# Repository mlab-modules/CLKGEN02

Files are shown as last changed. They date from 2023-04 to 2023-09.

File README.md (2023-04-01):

[Czech](./README.cs.md)
<!--- module --->
# CLKGEN02A
<!--- Emodule --->

<!--- subtitle --->Universal module for crystal oscillators<!--- Esubtitle --->

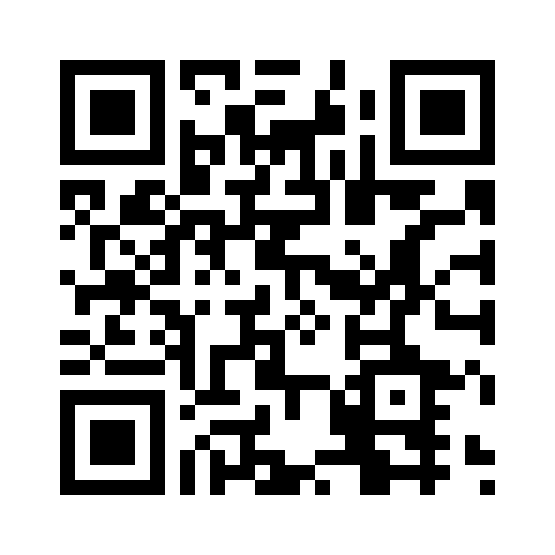
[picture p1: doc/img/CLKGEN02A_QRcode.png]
CLKGEN02A


<!--- description --->The module comprises a plurality of housings for mounting a variety of crystal oscillators.<!--- Edescription --->

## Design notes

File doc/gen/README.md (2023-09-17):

# PCB

Board size: 19.81x40.13 mm (0.78x1.58 inches)

- This is the size of the rectangle that contains the board
- Thickness: 1.6 mm (63 mils)
- Material: FR4
- Finish: HAL
- Layers: 2
- Copper thickness: 35 µm

Solder mask: TOP / BOTTOM

- Color: Green

Silk screen: TOP / BOTTOM

- Color: White

# Important sizes

Clearance: 0.2 mm (8 mils)

Track width: 0.3 mm (12 mils)

- By design rules: 0.2 mm (8 mils)

Drill: 0.5 mm (20 mils)

- Vias: 0.5 mm (20 mils) [Design: 0.4 mm (16 mils)]
- Pads: 0.7 mm (28 mils)
- The above values are real drill sizes, they add 0.1 mm (4 mils) to plated holes (PTH)

Via: 0.6/0.4 mm (24/16 mils)

- By design rules: 0.4/0.3 mm (16/12 mils)
- Micro via: yes [0.2/0.1 mm (8/4 mils)]
- Buried/blind via: yes
- Total: 5 (thru: 5 buried/blind: 0 micro: 0)

Outer Annular Ring: 0.05 mm (2 mils)

- By design rules: 0.26 mm (10 mils)

Eurocircuits class: 10B
- Using min drill 0.5 mm for an OAR of 0.05 mm

# General stats

Components count: (SMD/THT)

- Top: 0/8 (THT)
- Bottom: 6/7 (SMD + THT)

Defined tracks:

- 0.3 mm (12 mils)
- 0.4 mm (16 mils)
- 0.5 mm (20 mils)
- 0.6 mm (24 mils)
- 0.7 mm (28 mils)
- 0.8 mm (31 mils)
- 0.9 mm (35 mils)

Used tracks:

- 0.3 mm (12 mils) (23) defined: yes
- 0.9 mm (35 mils) (48) defined: yes

Defined vias:

Used vias:

- 0.6/0.4 mm (24/16 mils) (Count: 1, Aspect: 2.7 A) defined: no
- 0.8/0.4 mm (31/16 mils) (Count: 4, Aspect: 2.0 A) defined: no

Holes (excluding vias):

- 0.6 mm (24 mils) (4)
- 0.89 mm (35 mils) (14)
- 3.0 mm (118 mils) (4)

Oval holes:

Drill tools (including vias and computing adjusts and rounding):

- 0.5 mm (20 mils) (5)
- 0.7 mm (28 mils) (4)
- 1.0 mm (39 mils) (14)
- 3.1 mm (122 mils) (4)

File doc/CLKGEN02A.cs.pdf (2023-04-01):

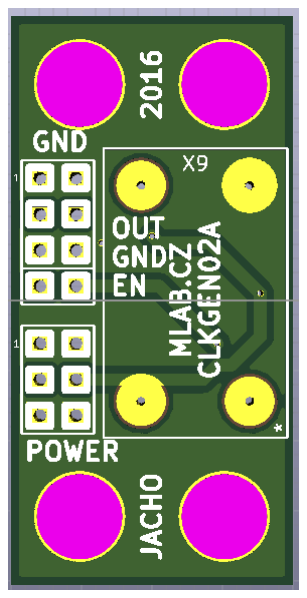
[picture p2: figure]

CLKGEN02A / 2017-02-20 / jacho/ http://www.mlab.cz | 1 / 4
CLKGEN02A | MLAB

# Krystalový oscilátor

Jan Chroust

Univerzální modul pro krystalový oscilátor s osmy typy pouzder.

# 1. Technické parametry

Parametr | Hodnota | Poznámka
Napájení | Dle zvoleného oscilátoru
Rozměry | 40.13 x 20.32 x 16 mm | Výška nad základní deskou

CLKGEN02A | MLAB

# 2. Popis konstrukce

## 2.1. Popis

Modul byl navržen jako univerzální pro osazení krystalovými oscilátory v osmy pouzdrech. Jedná se o tyto řady krystalových oscilátorů:

ASFL1
CFPS-72,73
ISM92 – R1=0R R2=nic
ISM97
I533_1534_1733_1734
ISM81
ISM95
OSC-F

CLKGEN02A | MLAB

## 2.2. Zapojení

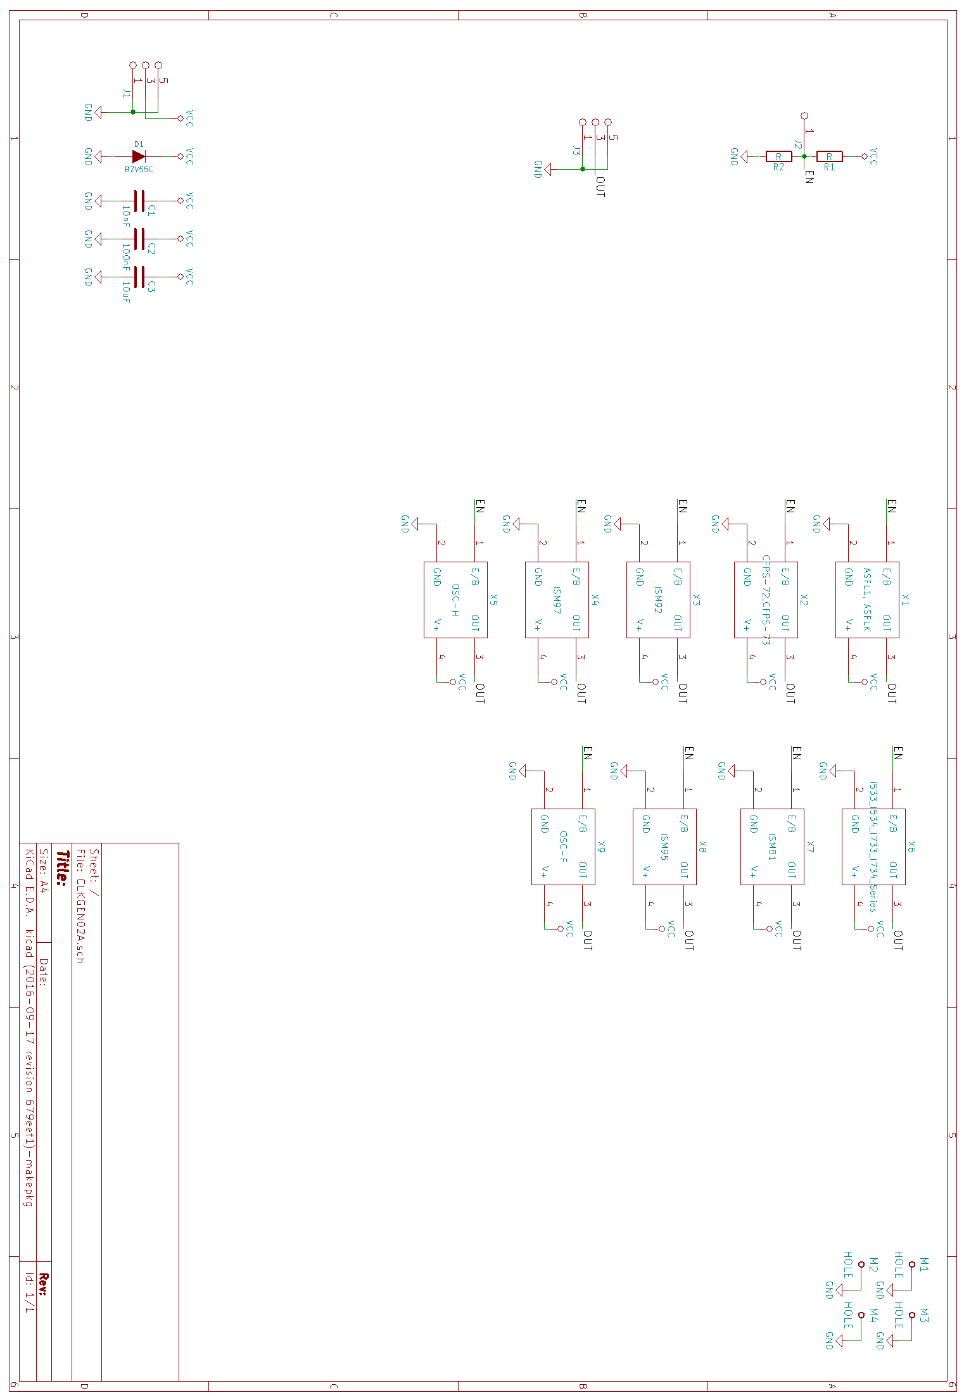
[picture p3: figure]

CLKGEN02A | MLAB

# 3. Osazení a oživení

## 3.1. Osazení

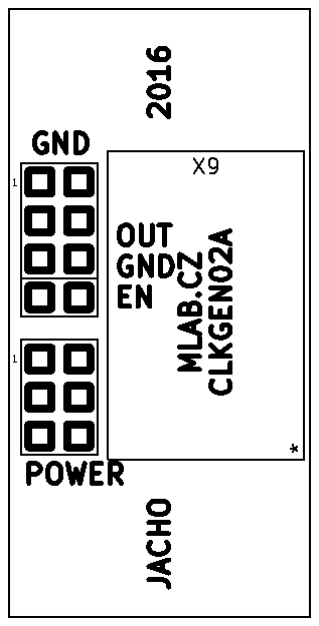
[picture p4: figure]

## 3.2. Rozpis součástek

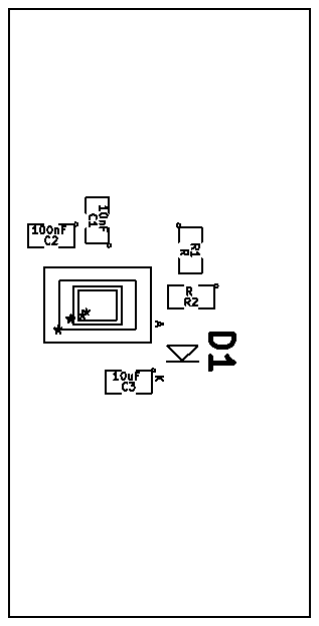
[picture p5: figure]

Označení | Typ | Pouzdro | Počet
C1 | 10nF | SMD-0805 | 1
C2 | 100nF | SMD-0805 | 1
C3 | 10uF | SMD-0805 | 1
J1,J3 | JUMP_3X2 | Straight_2x03 | 2
M1,M2,M3,M4 | HOLE | MountingHole_3mm | 4
R1,R2 | R | SMD-0805 | 2
X1 | ASFL1, ASFLK | ASFL1 | 1
X2 | CFPS-72,CFPS-73 | CFPS-72,73 | 1
X3 | ISM92 | ISM92 | 1
X4 | ISM97 | ISM97 | 1
X6 | I533_I534_I733_I734_Series | I533_1534_1733_1734 | 1
X7 | ISM81 | ISM81 | 1
X8 | ISM95 | ISM95 | 1
X9 | OSC-F | OSC-F | 1
J2 | JUMP_2x1 | Straight_1x02 | 1
D1 | BZV55C | Diode-MiniMELF_Standard | 1

## 3.3. Oživení

Není co oživovat. Je dobré provést kontrolu na zkraty.

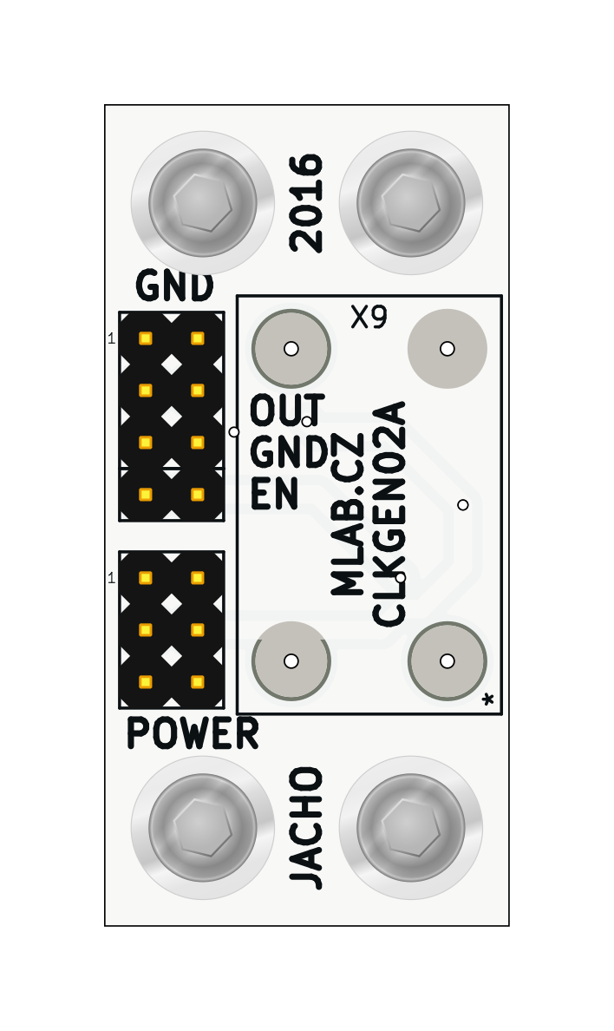
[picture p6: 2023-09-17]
doc/gen/img/CLKGEN02-top.png

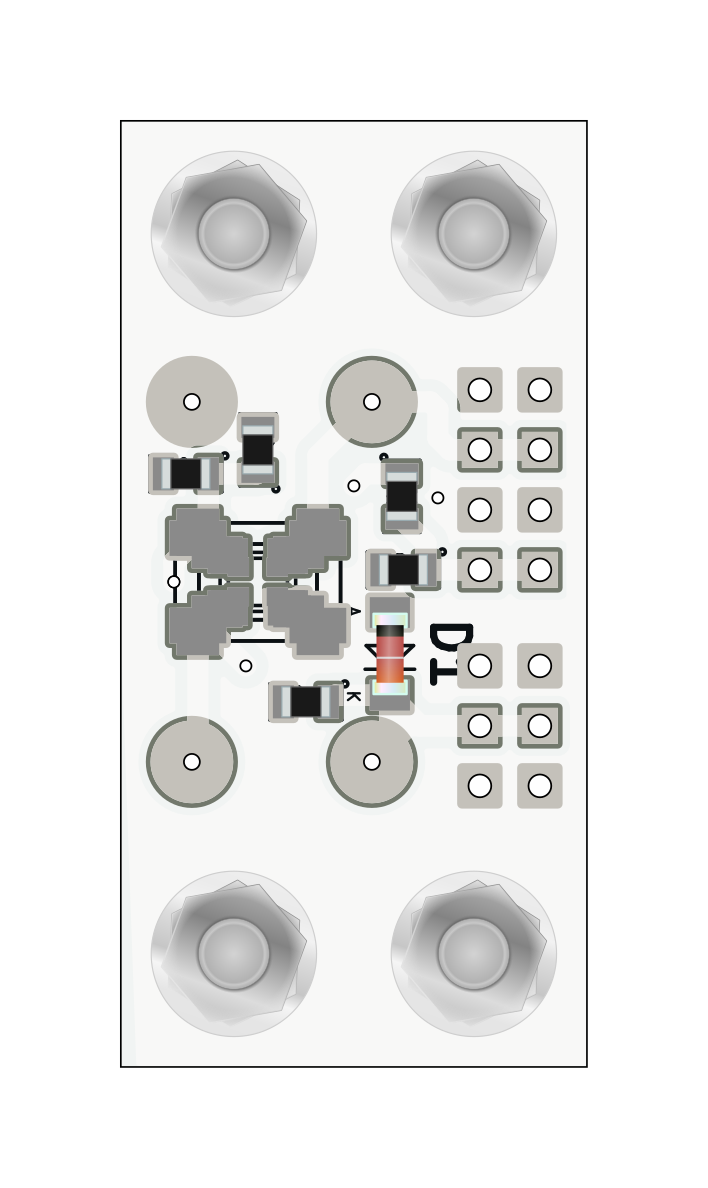
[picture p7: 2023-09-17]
doc/gen/img/CLKGEN02-bottom.png

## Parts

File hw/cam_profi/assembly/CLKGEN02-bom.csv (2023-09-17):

Component | Description | Part | References | Value | Footprint | Quantity Per PCB | Datasheet
1 |  | C | C1 | 10nF | SMD-0805 | 1
2 |  | C | C2 | 100nF | SMD-0805 | 1
3 |  | C | C3 | 10uF | SMD-0805 | 1
4 |  | DIODE | D1 | BZV55C | Diode-MiniMELF_Standard | 1
5 |  | JUMP_2x1 | J2 | JUMP_2x1 | Straight_1x02 | 1
6 |  | JUMP_3X2 | J1J3 | JUMP_3X2 | Straight_2x03 | 2
7 |  | R | R1R2 | R | SMD-0805 | 2
8 |  | IQXO/7X | X1 | ASFL1, ASFLK | ASFL1 | 1
9 |  | IQXO/7X | X2 | CFPS-72,CFPS-73 | CFPS-72,73 | 1
10 |  | IQXO/7X | X6 | I533_I534_I733_I734_Series | I533_1534_1733_1734 | 1
11 |  | IQXO/7X | X7 | ISM81 | ISM81 | 1
12 |  | IQXO/7X | X3 | ISM92 | ISM92 | 1
13 |  | IQXO/7X | X8 | ISM95 | ISM95 | 1
14 |  | IQXO/7X | X4 | ISM97 | ISM97 | 1
15 |  | IQXO/7X | X9 | OSC-F | OSC-F | 1
16 |  | IQXO/7X | X5 | OSC-H | OSC-H | 1

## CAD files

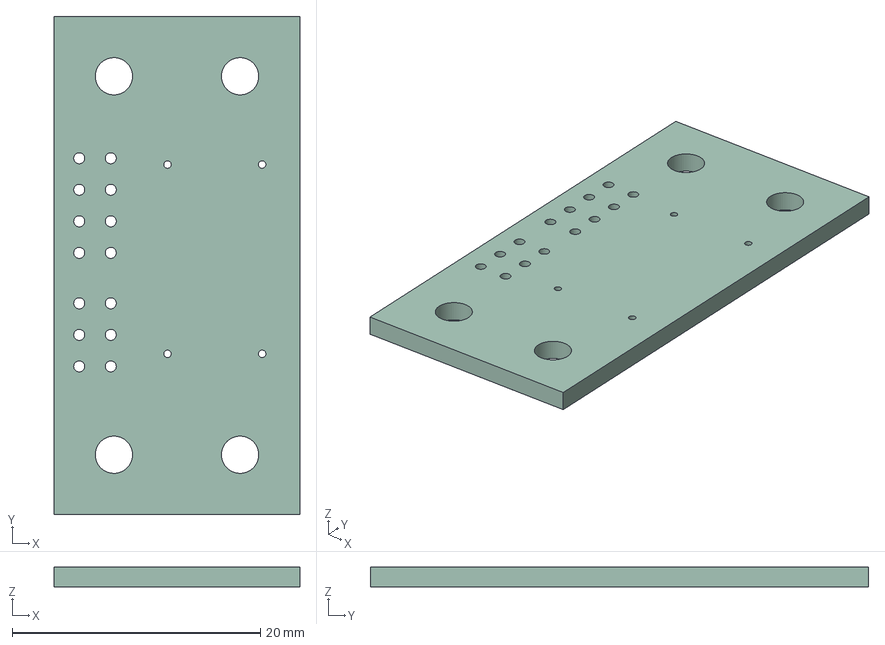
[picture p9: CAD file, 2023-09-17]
doc/gen/CLKGEN02.step
19.8 x 40.1 x 1.60 mm

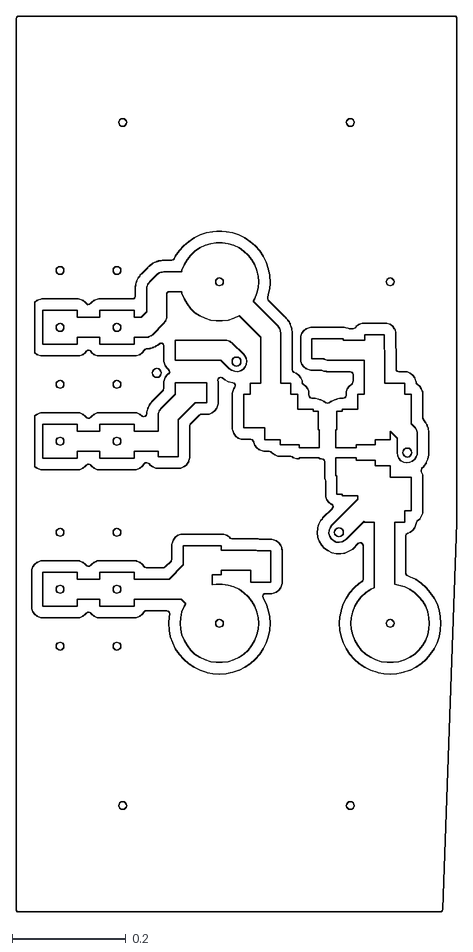
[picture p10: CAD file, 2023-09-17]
doc/gen/dxf/CLKGEN02-B_Cu.dxf
0.774 x 1.57

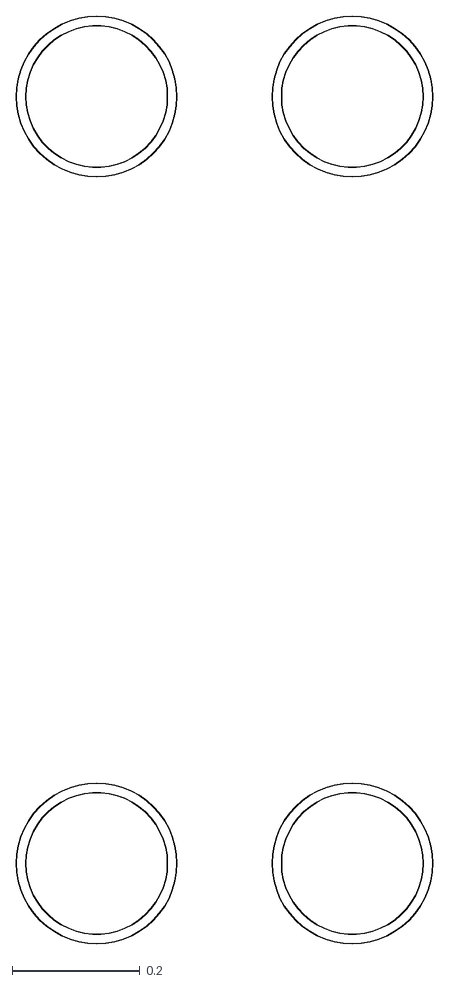
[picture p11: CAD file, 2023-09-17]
doc/gen/dxf/CLKGEN02-User_Comments.dxf
0.651 x 1.45

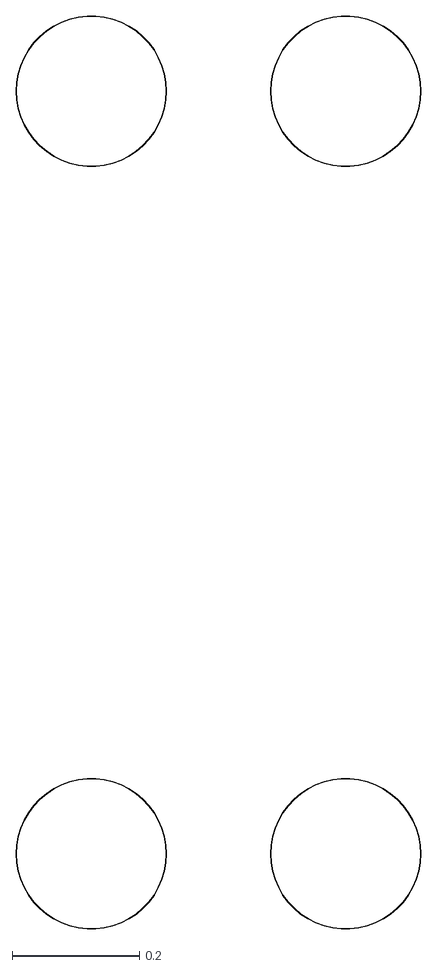
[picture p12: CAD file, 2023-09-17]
doc/gen/dxf/CLKGEN02-F_Adhesive.dxf
0.636 x 1.44

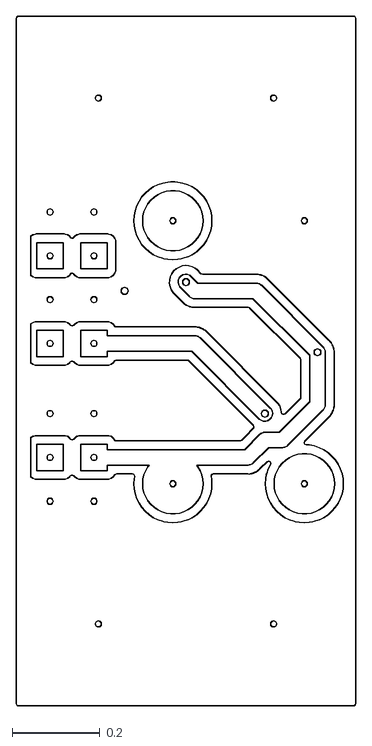
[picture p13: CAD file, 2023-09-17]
doc/gen/dxf/CLKGEN02-F_Cu.dxf
0.774 x 1.57

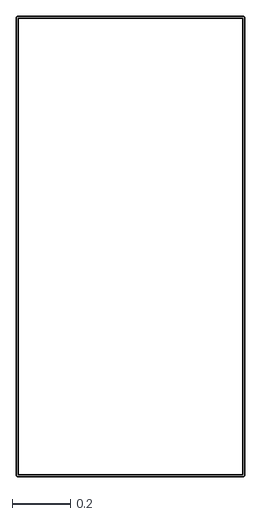
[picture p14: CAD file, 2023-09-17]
doc/gen/dxf/CLKGEN02-Edge_Cuts.dxf
0.786 x 1.59

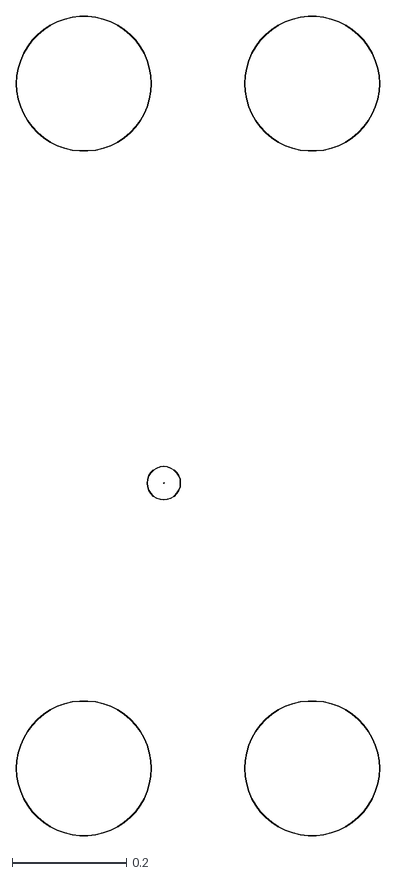
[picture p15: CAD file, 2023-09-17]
doc/gen/dxf/CLKGEN02-B_Adhesive.dxf
0.636 x 1.44

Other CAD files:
doc/gen/dxf/CLKGEN02-User_Drawings.dxf
doc/gen/dxf/CLKGEN02-Margin.dxf
doc/gen/dxf/CLKGEN02-B_Fab.dxf
doc/gen/dxf/CLKGEN02-F_Fab.dxf
doc/gen/dxf/CLKGEN02-B_Courtyard.dxf
doc/gen/dxf/CLKGEN02-User_Eco2.dxf
doc/gen/dxf/CLKGEN02-F_Courtyard.dxf
doc/gen/dxf/CLKGEN02-User_Eco1.dxf
doc/gen/dxf/CLKGEN02-B_Mask.dxf
doc/gen/dxf/CLKGEN02-B_Paste.dxf
doc/gen/dxf/CLKGEN02-B_Silkscreen.dxf
doc/gen/dxf/CLKGEN02-F_Mask.dxf
doc/gen/dxf/CLKGEN02-F_Paste.dxf
doc/gen/dxf/CLKGEN02-F_Silkscreen.dxf

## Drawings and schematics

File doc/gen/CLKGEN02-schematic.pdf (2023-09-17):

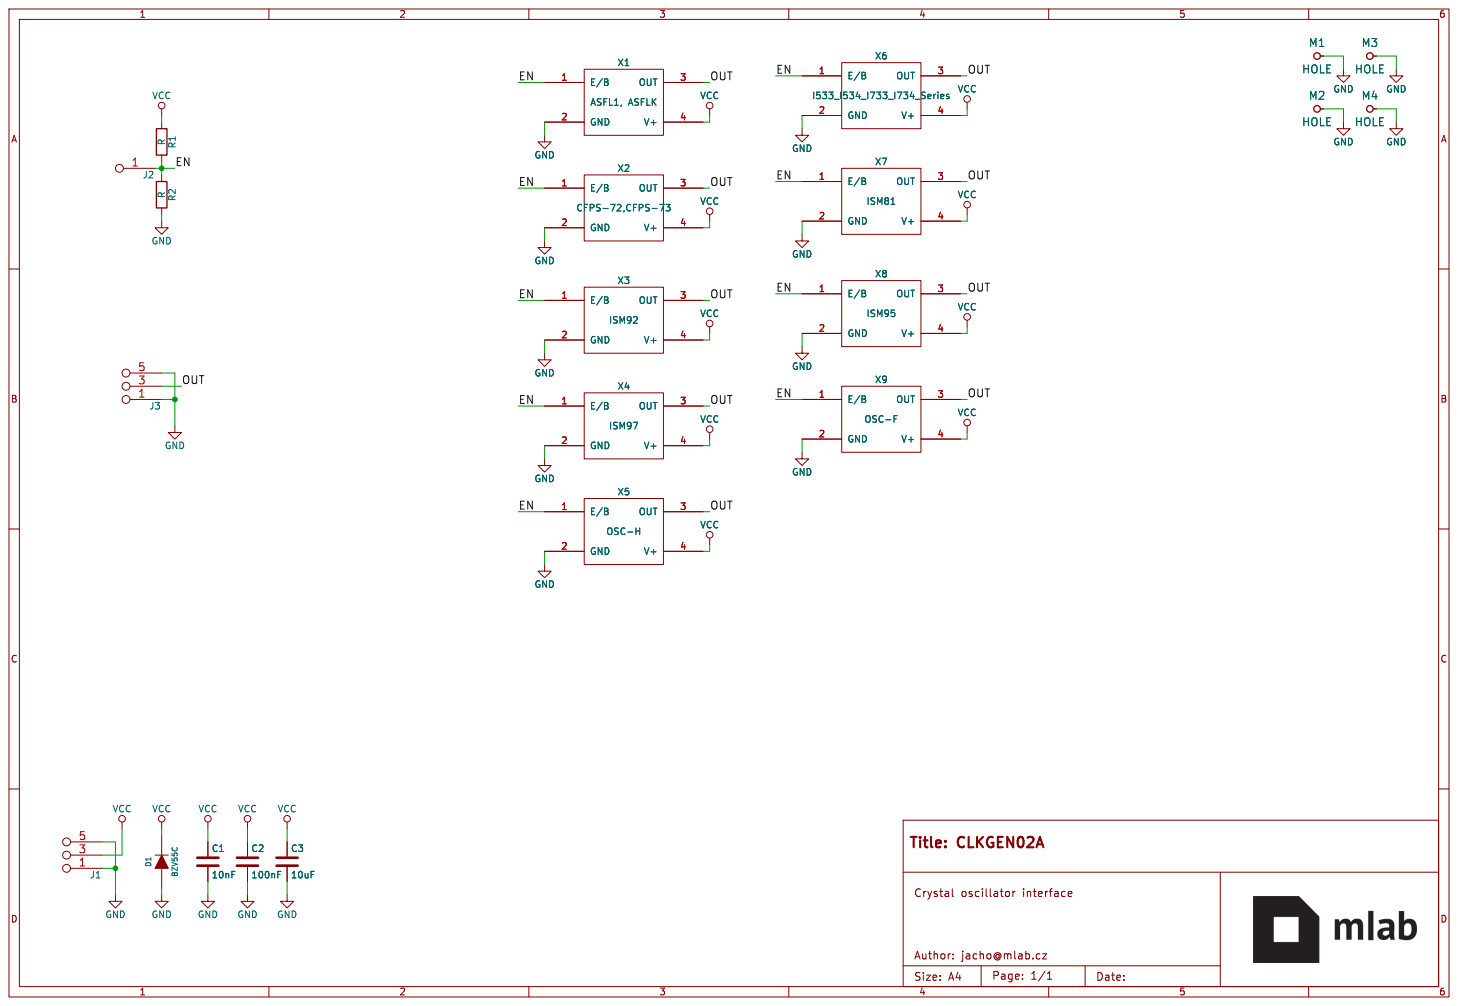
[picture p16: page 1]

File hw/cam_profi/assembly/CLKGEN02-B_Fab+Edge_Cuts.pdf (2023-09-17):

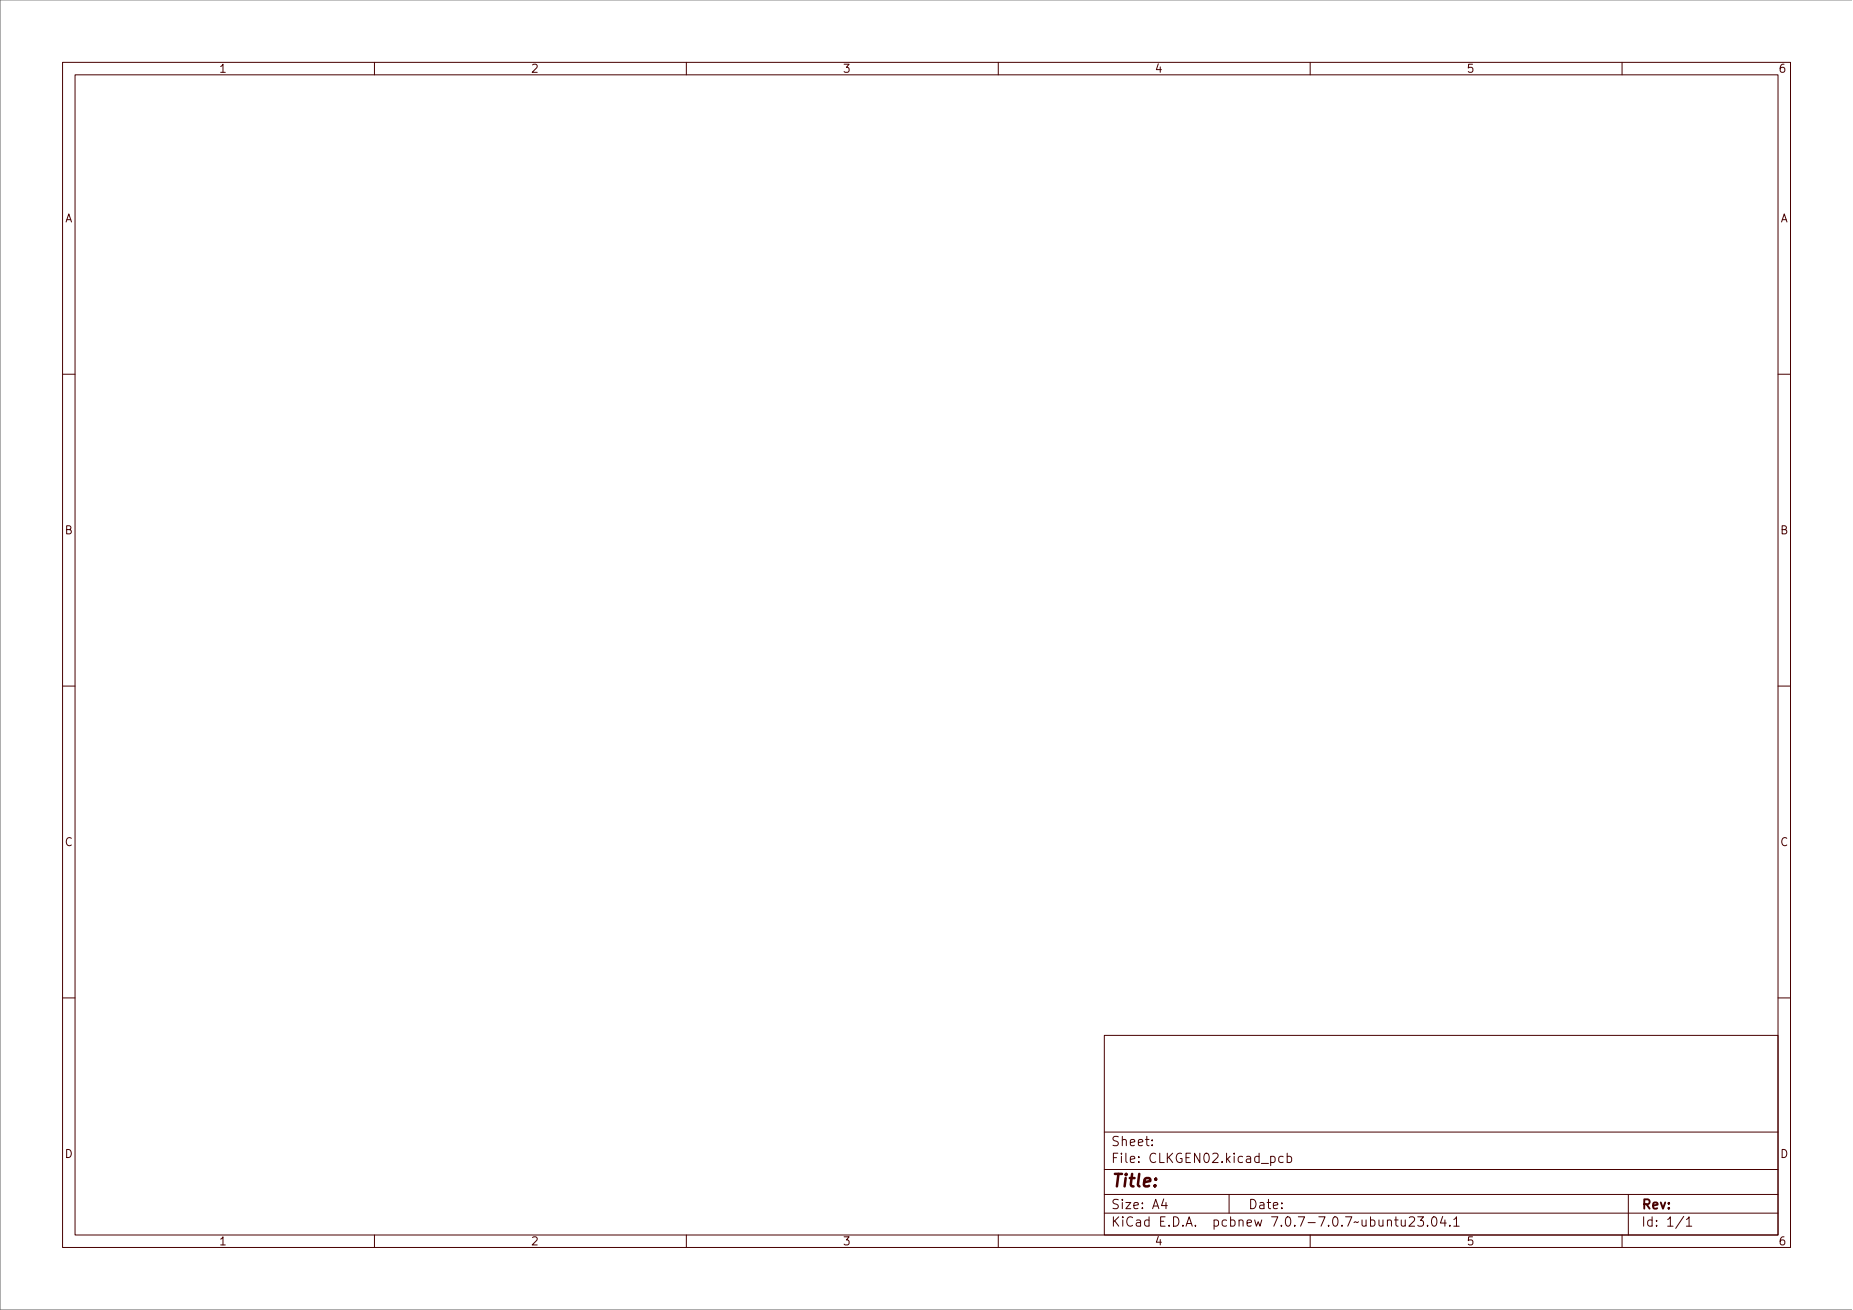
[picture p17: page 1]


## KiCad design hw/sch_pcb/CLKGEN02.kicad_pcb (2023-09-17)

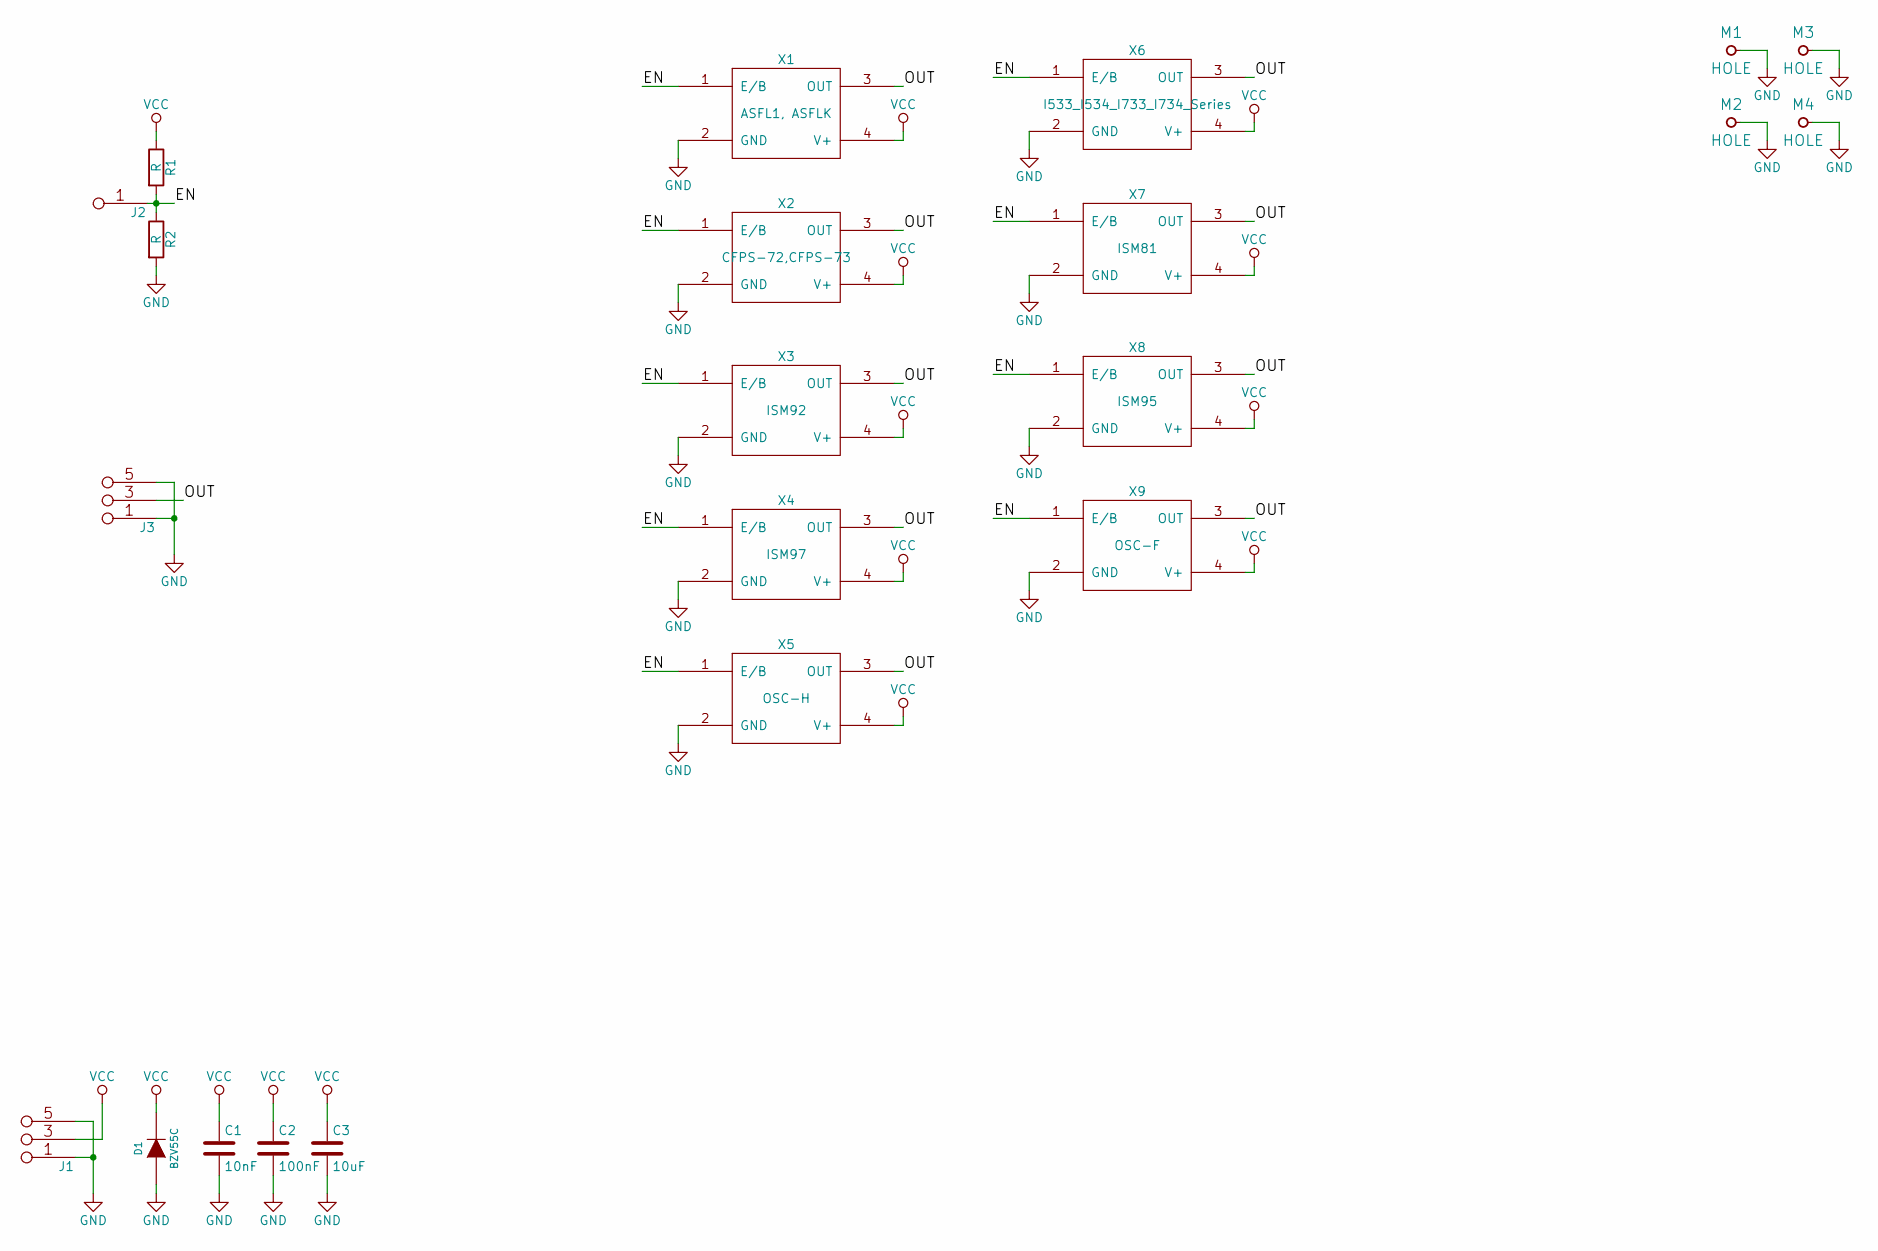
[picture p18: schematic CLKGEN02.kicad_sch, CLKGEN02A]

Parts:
C1: 10nF; SMD-0805
C2: 100nF; SMD-0805
C3: 10uF; SMD-0805
D1: BZV55C; Diode-MiniMELF_Standard
J1, J3: JUMP_3X2; Straight_2x03
J2: JUMP_2x1; Straight_1x02
M1, M2, M3, M4: HOLE; MountingHole_3mm
R1, R2: R; SMD-0805
X1: ASFL1, ASFLK; ASFL1
X2: CFPS-72,CFPS-73; CFPS-72,73
X3: ISM92
X4: ISM97
X5: OSC-H
X6: I533_I534_I733_I734_Series; I533_1534_1733_1734
X7: ISM81
X8: ISM95
X9: OSC-F

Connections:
/EN: J2.1, J2.2, R1.2, R2.1, X1.1 (E/B), X2.1 (E/B), X3.1 (E/B), X4.1 (E/B), X5.1 (E/B), X6.1 (E/B), X7.1 (E/B), X8.1 (E/B), X9.1 (E/B)
/OUT: J3.3 (4), J3.4, X1.3 (OUT), X2.3 (OUT), X3.3 (OUT), X4.3 (OUT), X5.3 (OUT), X6.3 (OUT), X7.3 (OUT), X8.3 (OUT), X9.3 (OUT)
GND: C1.2, C2.2, C3.2, D1.2 (A), J1.1 (2), J1.2, J1.5 (6), J1.6, J3.1 (2), J3.2, J3.5 (6), J3.6, M1.1, M2.1, M3.1, M4.1, R2.2, X1.2 (GND), X2.2 (GND), X3.2 (GND), X4.2 (GND), X5.2 (GND), X6.2 (GND), X7.2 (GND), X8.2 (GND), X9.2 (GND)
VCC: C1.1, C2.1, C3.1, D1.1 (K), J1.3 (4), J1.4, R1.1, X1.4 (V+), X2.4 (V+), X3.4 (V+), X4.4 (V+), X5.4 (V+), X6.4 (V+), X7.4 (V+), X8.4 (V+), X9.4 (V+)

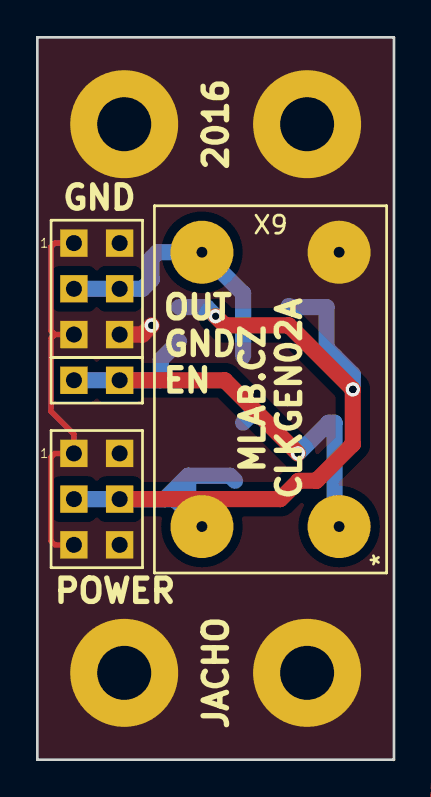
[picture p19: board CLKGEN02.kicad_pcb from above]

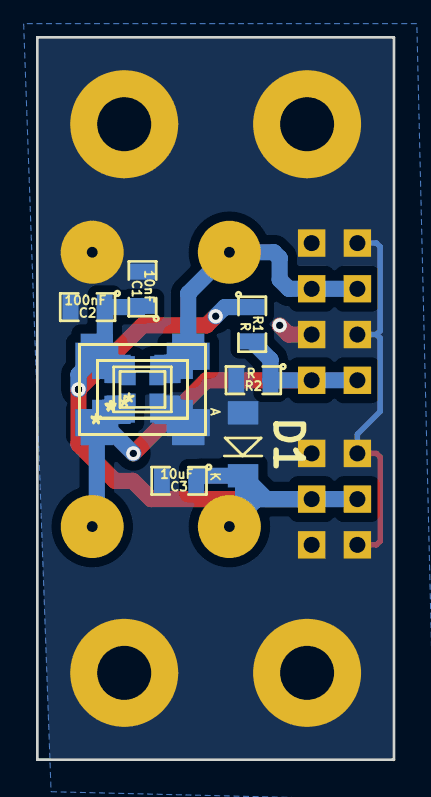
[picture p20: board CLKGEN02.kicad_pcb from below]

Board: 2 copper layers, 19.8 x 40.1 mm, 21 parts (13 on the bottom side), 4 nets.

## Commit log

2023-04-01 Adding force option to enable splitting in not fresh copy of Modules repository.
    [CLKGEN02A.kicad_pcb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]
2023-09-17 Convert project to new KiCAD7.
    [CLKGEN02.kicad_pcb, CLKGEN02.kicad_sch, CLKGEN02A.kicad_pcb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]
2023-09-17 Update actions products
    [CLKGEN02-B_Adhesive.dxf, CLKGEN02-B_Courtyard.dxf, CLKGEN02-B_Cu.dxf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]
